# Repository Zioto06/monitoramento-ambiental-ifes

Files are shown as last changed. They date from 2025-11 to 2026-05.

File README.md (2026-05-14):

# Monitoramento Ambiental IFES

> Esse projeto consiste no sistema de monitoramento ambiental desenvolvido para salas de servidores, utilizando [ESP32](https://www.espressif.com/en/products/socs/esp32) como `agente SNMP`, serviço de coleta em Python, armazenamento em banco de dados e visualização via aplicação web. 
>
> O rojeto foi desenvolvido no IFES, Campus Guarapari, na disciplina de Projetos Aplicados.
>
> Integrantes:
>
> - Daniel Prezotti Marchesi
> - Gustavo Delpupo Ribeiro
> - João Pedro Queiroz dos Santos 
> - Luis Philipe Zioto de Barros
>
> Orientador:
> - Bruno Neves Amigo
>
---

# Visão Geral

Este projeto realiza o monitoramento contínuo de temperatura e umidade utilizando sensores DHT acoplados a um ESP32, que atua como `agente SNMP`. Um serviço em Python consulta periodicamente o dispositivo, grava os registros em um banco MySQL e disponibiliza uma `aplicação web` para visualização em tempo real, análise histórica e log de eventos acima dos limiares configurados. O sistema possui:

- Monitoramento contínuo (ESP32 + DHT);
- Consulta remota em tempo real (SNMP GET);
- Registro histórico em banco de dados;
- Alertas via e-mail (SMTP);
- Gráficos de série histórica;
- Log de eventos críticos;
- Interface web desenvolvida com Flask + Chart.js.

---

# Arquitetura do Sistema

A arquitetura do sistema segue estruturada em partes que funcionam de forma integrada para permitir o monitoramento ambiental em tempo real. Cada camada possui uma função específica dentro do fluxo geral do sistema, desde o sensoriamento físico até a visualização dos dados pelo usuário final.

---

## 1. Estrutura de Hardware

Essa camada é responsável pela aquisição das variáveis ambientais. Ela é composta pelos sensores digitais `DHT11` e `DHT22`, conectados a um `ESP32` (via one-wire), além de um `display OLED` (via I2C) utilizado para exibição local e um botão físico para ativar/desativar o display.

A imagem a seguir apresenta a organização do módulo de hardware:

<div align="center">
  
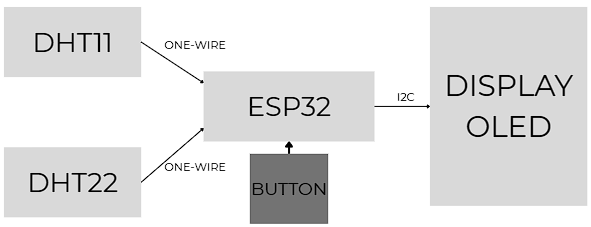
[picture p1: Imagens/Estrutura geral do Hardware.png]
Estrutura geral do Hardware


</div>

---

## 2. Software Embarcado na ESP

O ESP32 executa um sistema embarcado desenvolvido especificamente para este projeto, sendo responsável por:

- Realizar leituras periódicas dos sensores;
- Organizar o funcionamento interno em tarefas separadas (FreeRTOS);
- Manter a conexão Wi-Fi ativa com tentativa de reconexão;
- Disponibilizar as variáveis ambientais na rede por meio do **protocolo SNMP**, operando como **Agente SNMP**.

---

## 3. Serviço de Coleta, Armazenamento no Banco de Dados e Alertas SMTP

No servidor roda um serviço desenvolvido em Python, responsável por:

- Consultar periodicamente a ESP32 via SNMP;
- Registrar cada leitura em um `banco de dados MySQL;
- Verificar condições de alerta (ex.: temperatura acima do limite configurado);
- Enviar notificações por e-mail via `SMTP` sempre que necessário.

Essa organização permite manter um histórico completo das variáveis coletadas e automatizar o processo de notificação.

A figura seguinte apresenta o fluxo lógico entre os módulos:

<div align="center">

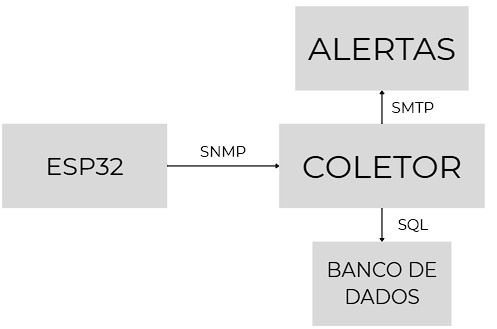
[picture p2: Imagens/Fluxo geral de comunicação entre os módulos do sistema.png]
Fluxo geral de comunicação entre os módulos do sistema


</div>

---

## 4. Aplicação Web e Interação com Usuários

A aplicação web funciona como o módulo de apresentação, permitindo ao usuário:

- Visualizar as medições em `tempo real` diretamente da ESP32;
- Acessar gráficos com `todas as leituras armazenadas` no banco de dados;
- Consultar registros específicos de valores acima do limite definido.

A aplicação organiza e exibe as informações de modo simples, atualizável e acessível via navegador.

A figura abaixo resume a interação entre a aplicação e os demais componentes:

<div align="center">
  
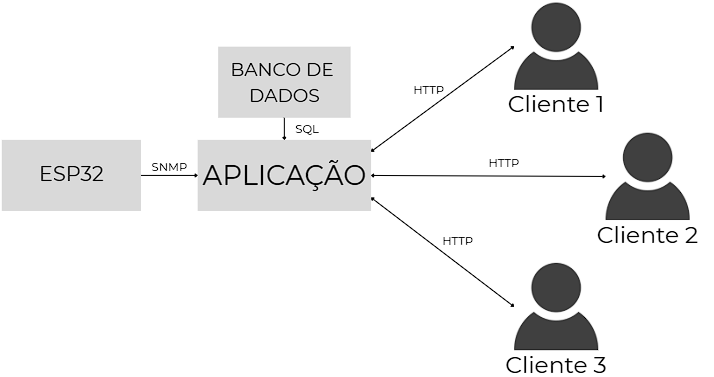
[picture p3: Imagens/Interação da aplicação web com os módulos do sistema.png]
Interação da aplicação web com os módulos do sistema


</div>

---

# Estrutura do Projeto e Descrição dos Arquivos

A organização das pastas e arquivos segue um padrão simples e objetivo para facilitar manutenção, execução e entendimento do sistema de monitoramento.

README.md

Imagens/

monitoramento/

```bash
static/
└── image.jpg

templates/
├── acima23.html
├── index.html
└── instantaneo.html

├── env
├── Atualizado.ino
├── DDL_leitura.sql
├── PA3.sch
├── app.py
├── coletor_snmp.py
├── modelo3d.f3d
└── requirements.txt
```

---

## static
Contém arquivos estáticos usados no painel web.

- image.jpg: Imagem exibida no rodapé das páginas HTML.

---

## templates
Contém todas as páginas HTML renderizadas pelo Flask.

- **index.html**: Página da *Série Histórica* com gráficos de temperatura e umidade.  
- **instantaneo.html**: Página *Tempo Real*, leitura SNMP direta da ESP32.  
- **acima23.html**: Página do *Log de Eventos*, exibindo leituras acima do limiar.

Todas utilizam o sistema de navegação por abas (Tempo Real, Série Histórica, Log de Eventos).

---

## Atualizado.ino
Arquivo de firmware para a ESP32, responsável por:

- Ler os sensores DHT11 e DHT22;  
- Exibir dados no display OLED;  
- Publicar temperatura e umidade via SNMP;  
- Gerenciar reconexão Wi-Fi;  
- Executar tarefas via FreeRTOS. 

Este arquivo deve ser enviado para a placa ESP32.

---

## DDL_leitura.sql
Script SQL que:

- Cria o banco de dados;  
- Cria a tabela de leituras;  
- Cria um usuário com acesso somente SELECT.

O arquivo é genérico e permite personalização de nomes e credenciais.

---

## PA3.sch

Arquivo de esquema elétrico criado no Autodesk EAGLE, contendo o circuito de interligação entre microcontrolador, sensores, display e demais componentes do protótipo.

---

## app.py
Aplicação Flask que:

- Disponibiliza todas as páginas HTML;  
- Fornece APIs JSON para os gráficos (`/api/...`);  
- Consulta leituras no MySQL;  
- Exibe leituras da ESP32 em tempo real via SNMP.  

É a interface web do sistema como um todo.

Todas as configurações vêm do arquivo @.env.

---

## coletor_snmp.py
Serviço Python que:

- Consulta a ESP32 via SNMP periodicamente;  
- Grava as leituras no MySQL;  
- Envia alertas por e-mail quando limites são ultrapassados;  
- Executa continuamente e registra logs.  

Todas as configurações vêm do arquivo `env`.

---

## modelo3d.f3d

Arquivo de modelagem tridimensional desenvolvido no Autodesk Fusion 360, representando o invólucro da caixa utilizado para acomodar e fixar o módulo de hardware.

---

## env
Arquivo com todas as configurações externas:

- IP da ESP32;  
- Comunidade SNMP;  
- OIDs dos sensores;  
- Credenciais MySQL;  
- Limiares de alerta;  
- Configurações SMTP;  
- Porta do servidor Flask.  

*O usuário deve ajustar este arquivo antes de rodar o sistema*.

---

## requirements.txt
O sistema usa apenas três bibliotecas Python:

- **Flask**: para rodar a aplicação web.
- **mysql-connector-python**: para conectar ao banco MySQL.
- **python-dotenv**: para carregar variáveis do arquivo `.env`.

Essas três dependências são suficientes para executar todo o projeto.

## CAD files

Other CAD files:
monitoramento/modelo3d.f3d

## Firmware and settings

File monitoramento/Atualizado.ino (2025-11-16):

/*******************************************************
 * PROJETO Monitoramento Ambiental – ESP32 + SNMP + OLED
 * FUNÇÕES:
 *  - Lê temperatura/umidade (DHT11/DHT22)
 *  - Exibe no OLED (SSD1306, I²C)
 *  - Publica via SNMP (UDP/161) como inteiros escalados (×10)
 *  - Estrutura com FreeRTOS: tarefa dedicada à leitura do sensor
 *
 *  PONTOS PARA CONFIGURAR
 *   - WIFI_SSID / WIFI_PASSWORD
 *   - Pinos dos DHT se forem diferentes
 *   - Endereço I2C do OLED se não for 0x3C
 *   - OIDs SNMP, se quiser mudar a árvore
 *******************************************************/

 /*******************************************************
 * BIBLIOTECAS NECESSÁRIAS PARA O CÓDIGO DA ESP32
 *
 * - WiFi.h               (já incluída no core ESP32)
 * - WiFiUdp.h            (já incluída no core ESP32)
 * - Wire.h               (já incluída no core ESP32)
 *
 * - DHT.h                -> instalar: "DHT sensor library" (Adafruit)
 * - Adafruit_GFX.h       -> instalar: "Adafruit GFX Library"
 * - Adafruit_SSD1306.h   -> instalar: "Adafruit SSD1306"
 *
 * - SNMP_Agent.h         -> instalar manualmente (biblioteca externa para SNMP)
 *
 * OBS.: O código deve ser compilado usando ESP32 Core 2.x na IDE Arduino.
 *******************************************************/


#include <WiFi.h>
#include <WiFiUdp.h>
#include <SNMP_Agent.h>
#include <DHT.h>
#include <Wire.h>
#include <Adafruit_GFX.h>
#include <Adafruit_SSD1306.h>

/********** DISPLAY OLED (I2C) **********/
#define SCREEN_WIDTH 128
#define SCREEN_HEIGHT 64
#define OLED_RESET    -1
#define OLED_I2C_ADDR 0x3C

// Pinos I2C conforme o SEU hardware (ESP32)
#define OLED_SDA 18
#define OLED_SCL 19

Adafruit_SSD1306 display(SCREEN_WIDTH, SCREEN_HEIGHT, &Wire, OLED_RESET);

/********** SENSORES DHT **********/
// Ajuste os pinos conforme sua montagem
#define DHTPIN1   4      // DHT11
#define DHTTYPE1  DHT11
#define DHTPIN2   2      // DHT22
#define DHTTYPE2  DHT22

DHT dht1(DHTPIN1, DHTTYPE1);
DHT dht2(DHTPIN2, DHTTYPE2);

/********** REDE WI-FI **********/
// ALTERE PARA SUA REDE
const char* ssid     = "SEU_SSID_AQUI";
const char* password = "SUA_SENHA_AQUI";

/********** SNMP **********/
WiFiUDP udp;

// Comunidade pública genérica (pode mudar no seu NMS)
SNMPAgent snmp = SNMPAgent("public", "private");

// 🔧 OIDs SNMP – ajuste se quiser mudar a MIB
const char* OID_TEMPERATURA1 = ".1.3.6.1.4.1.99999.1.0";
const char* OID_UMIDADE1     = ".1.3.6.1.4.1.99999.1.1";
const char* OID_TEMPERATURA2 = ".1.3.6.1.4.1.99999.1.2";
const char* OID_UMIDADE2     = ".1.3.6.1.4.1.99999.1.3";

// Handlers SNMP
ValueCallback* temperature1OID = nullptr;
ValueCallback* humidity1OID    = nullptr;
ValueCallback* temperature2OID = nullptr;
ValueCallback* humidity2OID    = nullptr;

// Variáveis publicadas no SNMP (×10). Use mutex ao acessar!
int temperature1_x10 = 0; // ex.: 251 = 25,1 °C
int humidity1_x10    = 0; // ex.: 678 = 67,8 %
int temperature2_x10 = 0;
int humidity2_x10    = 0;

/********** SINCRONIZAÇÃO (FreeRTOS) **********/
SemaphoreHandle_t xMutex = nullptr;

/********** TAREFA DE LEITURA **********/
void readDHTTask(void * pvParameters);

/********** FUNÇÕES AUXILIARES **********/
void drawBootScreen();
void drawStatusScreen(float t1, float h1, float t2, float h2, bool okRead1, bool okRead2);
void ensureWiFi();

/*******************************************************
 * setup()
 *******************************************************/
void setup() {
  Serial.begin(115200);
  delay(100);

  // I2C + OLED
  Wire.begin(OLED_SDA, OLED_SCL);
  if (!display.begin(SSD1306_SWITCHCAPVCC, OLED_I2C_ADDR)) {
    Serial.println(F("[OLED] Falha na inicialização do SSD1306"));
    for (;;) { delay(1000); }
  }
  display.clearDisplay();
  display.display();
  drawBootScreen();

  // Wi-Fi
  WiFi.mode(WIFI_STA);
  WiFi.begin(ssid, password);
  Serial.printf("[WiFi] Conectando-se a %s\n", ssid);

  int attempts = 0;
  const int max_attempts = 30;
  while (WiFi.status() != WL_CONNECTED && attempts < max_attempts) {
    delay(500);
    Serial.print(".");
    attempts++;
  }
  Serial.println();

  if (WiFi.status() == WL_CONNECTED) {
    Serial.printf("[WiFi] Conectado, IP: %s\n", WiFi.localIP().toString().c_str());
  } else {
    Serial.println("[WiFi] Falha na conexão. Reiniciando em 3s...");
    delay(3000);
    ESP.restart();
  }

  // Mostra IP no OLED
  display.clearDisplay();
  display.setTextSize(1);
  display.setTextColor(SSD1306_WHITE);
  display.setCursor(0, 0);
  display.print("IP: ");
  display.println(WiFi.localIP().toString());
  display.display();

  // Sensores
  dht1.begin();
  dht2.begin();

  // SNMP
  snmp.setUDP(&udp);
  snmp.begin();

  // Registra OIDs (inteiros ×10)
  temperature1OID = snmp.addIntegerHandler(OID_TEMPERATURA1, &temperature1_x10);
  humidity1OID    = snmp.addIntegerHandler(OID_UMIDADE1,     &humidity1_x10);
  temperature2OID = snmp.addIntegerHandler(OID_TEMPERATURA2, &temperature2_x10);
  humidity2OID    = snmp.addIntegerHandler(OID_UMIDADE2,     &humidity2_x10);

  snmp.sortHandlers();

  // Mutex
  xMutex = xSemaphoreCreateMutex();
  if (xMutex == NULL) {
    Serial.println("[RTOS] Falha ao criar mutex. Reiniciando...");
    delay(2000);
    ESP.restart();
  }

  // Tarefa de leitura (3 KB stack, prioridade 1)
  BaseType_t ok = xTaskCreate(
      readDHTTask,
      "ReadDHTTask",
      3072,
      NULL,
      1,
      NULL
  );
  if (ok != pdPASS) {
    Serial.println("[RTOS] Falha ao criar tarefa de leitura. Reiniciando...");
    delay(2000);
    ESP.restart();
  }
}

/*******************************************************
 * loop()
 * - Mantém SNMP e checa Wi-Fi
 *******************************************************/
void loop() {
  ensureWiFi();

  // Processa SNMP com proteção rápida
  if (xSemaphoreTake(xMutex, (TickType_t)10) == pdTRUE) {
    snmp.loop();
    xSemaphoreGive(xMutex);
  }

  vTaskDelay(pdMS_TO_TICKS(10)); // respiro
}

/*******************************************************
 * TAREFA: readDHTTask
 *******************************************************/
void readDHTTask(void * pvParameters) {
  const TickType_t period = pdMS_TO_TICKS(2000); // 2s entre leituras

  for (;;) {
    float t1 = dht1.readTemperature();
    float h1 = dht1.readHumidity();
    float t2 = dht2.readTemperature();
    float h2 = dht2.readHumidity();

    bool ok1 = !(isnan(t1) || isnan(h1));
    bool ok2 = !(isnan(t2) || isnan(h2));

    if (xSemaphoreTake(xMutex, portMAX_DELAY) == pdTRUE) {
      if (ok1) {
        int t1x = (int)(t1 * 10.0f);
        int h1x = (int)(h1 * 10.0f);
        if (t1x > 999) t1x = 999; if (t1x < -999) t1x = -999;
        if (h1x > 999) h1x = 999; if (h1x < 0)    h1x = 0;
        temperature1_x10 = t1x;
        humidity1_x10    = h1x;
      }
      if (ok2) {
        int t2x = (int)(t2 * 10.0f);
        int h2x = (int)(h2 * 10.0f);
        if (t2x > 999) t2x = 999; if (t2x < -999) t2x = -999;
        if (h2x > 999) h2x = 999; if (h2x < 0)    h2x = 0;
        temperature2_x10 = t2x;
        humidity2_x10    = h2x;
      }

      // Atualiza OLED
      drawStatusScreen(t1, h1, t2, h2, ok1, ok2);

      xSemaphoreGive(xMutex);
    }

    vTaskDelay(period);
  }
}

/*******************************************************
 * ensureWiFi()
 *******************************************************/
void ensureWiFi() {
  static unsigned long lastCheck = 0;
  const unsigned long interval = 5000;

  unsigned long now = millis();
  if (now - lastCheck < interval) return;
  lastCheck = now;

  if (WiFi.status() != WL_CONNECTED) {
    Serial.println("[WiFi] Perda de conexão. Tentando reconectar...");
    WiFi.disconnect(true, true);
    WiFi.begin(ssid, password);

    int tries = 0;
    while (WiFi.status() != WL_CONNECTED && tries < 20) {
      vTaskDelay(pdMS_TO_TICKS(10));
      Serial.print(".");
      tries++;
    }
    Serial.println();
    if (WiFi.status() == WL_CONNECTED) {
      Serial.printf("[WiFi] Reconectado. IP: %s\n", WiFi.localIP().toString().c_str());
    } else {
      Serial.println("[WiFi] Sem conexão. Reiniciando em 5s...");
      vTaskDelay(pdMS_TO_TICKS(5000));
      ESP.restart();
    }
  }
}

/*******************************************************
 * drawBootScreen()
 *******************************************************/
void drawBootScreen() {
  display.clearDisplay();
  display.setTextSize(1);
  display.setTextColor(SSD1306_WHITE);
  display.setCursor(0, 0);
  display.println("Monitor Ambiental");
  display.println("ESP32 + SNMP + OLED");
  display.setCursor(0, 24);
  display.println("Conectando Wi-Fi...");
  display.display();
}

/*******************************************************
 * drawStatusScreen(...)
 *******************************************************/
void drawStatusScreen(float t1, float h1, float t2, float h2, bool okRead1, bool okRead2) {
  display.clearDisplay();
  display.setTextSize(1);
  display.setTextColor(SSD1306_WHITE);

  // IP
  display.setCursor(0, 0);
  display.print("IP: ");
  display.println(WiFi.localIP().toString());

  // Sensor 1
  display.setCursor(0, 16);
  display.print("S1 (DHT11):");
  display.setCursor(0, 26);
  if (okRead1) {
    display.print("T1: "); display.print(t1, 1); display.print("C  ");
    display.print("H1: "); display.print(h1, 1); display.println("%");
  } else {
    display.println("T1/H1: ERROR");
  }

  // Sensor 2
  display.setCursor(0, 42);
  display.print("S2 (DHT22):");
  display.setCursor(0, 52);
  if (okRead2) {
    display.print("T2: "); display.print(t2, 1); display.print("C  ");
    display.print("H2: "); display.print(h2, 1); display.print("%");
  } else {
    display.println("T2/H2: ERROR");
  }

  display.display();
}
